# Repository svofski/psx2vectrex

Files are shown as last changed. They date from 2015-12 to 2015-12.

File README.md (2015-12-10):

# psx2vectrex

This project allows using a classic PlayStation controller with Vectrex. 

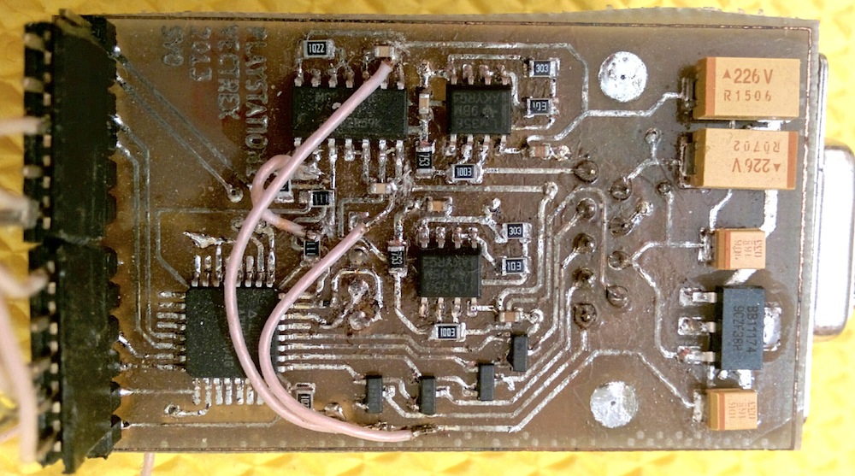
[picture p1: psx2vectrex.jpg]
Rusty PCB


Parts list:
 * 1x ATmega8
 * 1x MCP42010 dual-channel digital potentiometer
 * 2x LM358 opamp
 * 4x IRLML2502 (or any similar) logic-level n-channel MOSFETs
 * 1x LM1117-3V3 LDO, or equivalent
 * Some resistors and capacitors
 
Circuit in [PDF file](/kicad/vectrexmando.pdf)

The hardware is done in KiCAD. The design files are in [kicad](/kicad) directory.

To compile the source code WinAVR or avr-gcc/avr-libc is required. A programmer of choice is required to
bootstrap the microcontroller.

This adapter works excellent for me, but it's probably an overkill of a circuit for something as simple as this.

Here's a test video:

Joystick test video (http://www.youtube.com/watch?v=Hoa-xzlJ_dA)

---

2013-2015 Viacheslav Slavinsky, http://sensi.org/~svo

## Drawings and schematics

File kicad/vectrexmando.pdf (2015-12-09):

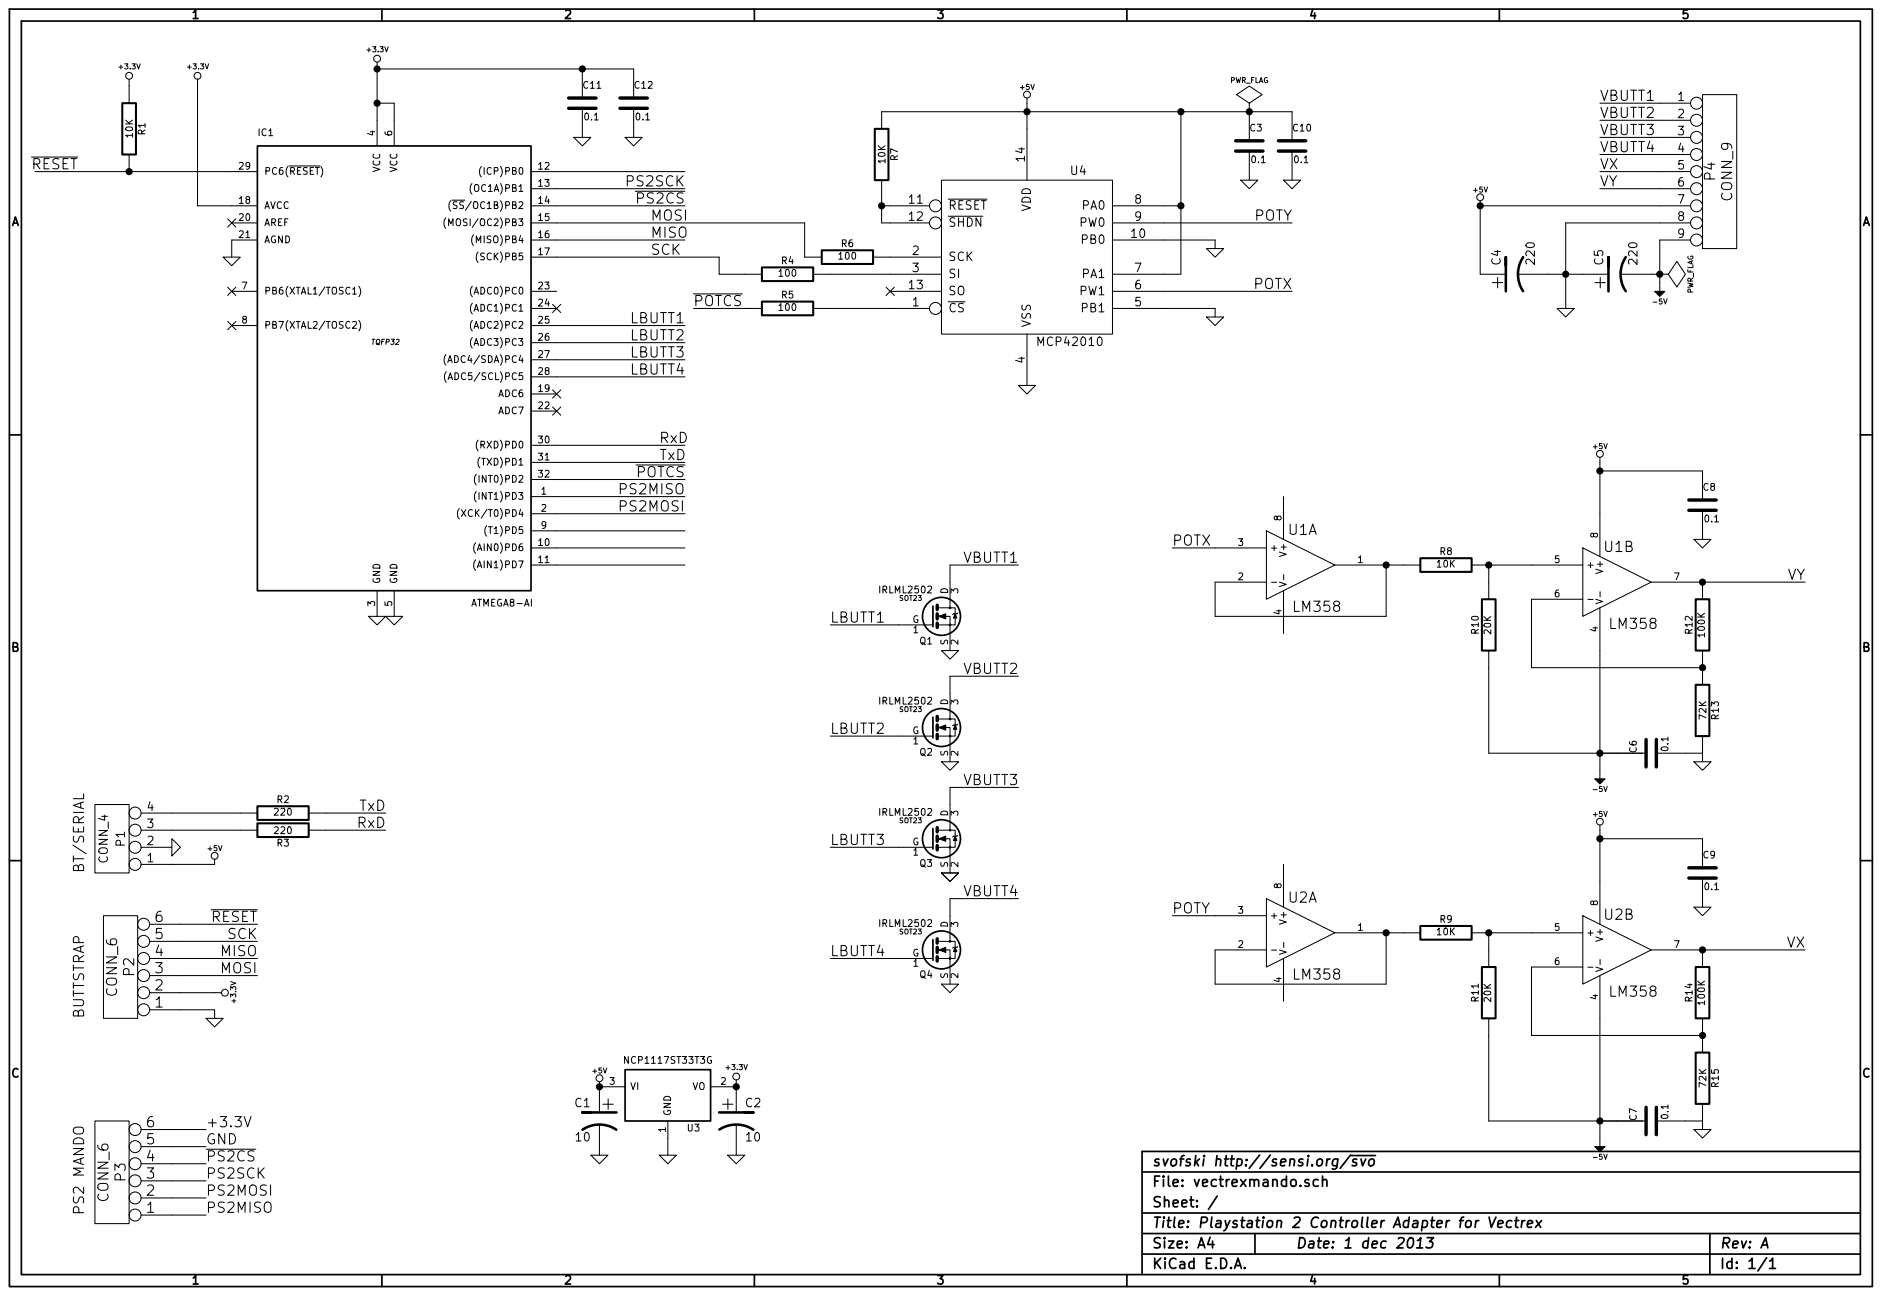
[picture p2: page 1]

LBUTT3
LBUTT4

svofski http://sensi.org/svo
Title: Playstation 2 Controller Adapter for Vectrex File: vectrexmando.sch Sheet: /

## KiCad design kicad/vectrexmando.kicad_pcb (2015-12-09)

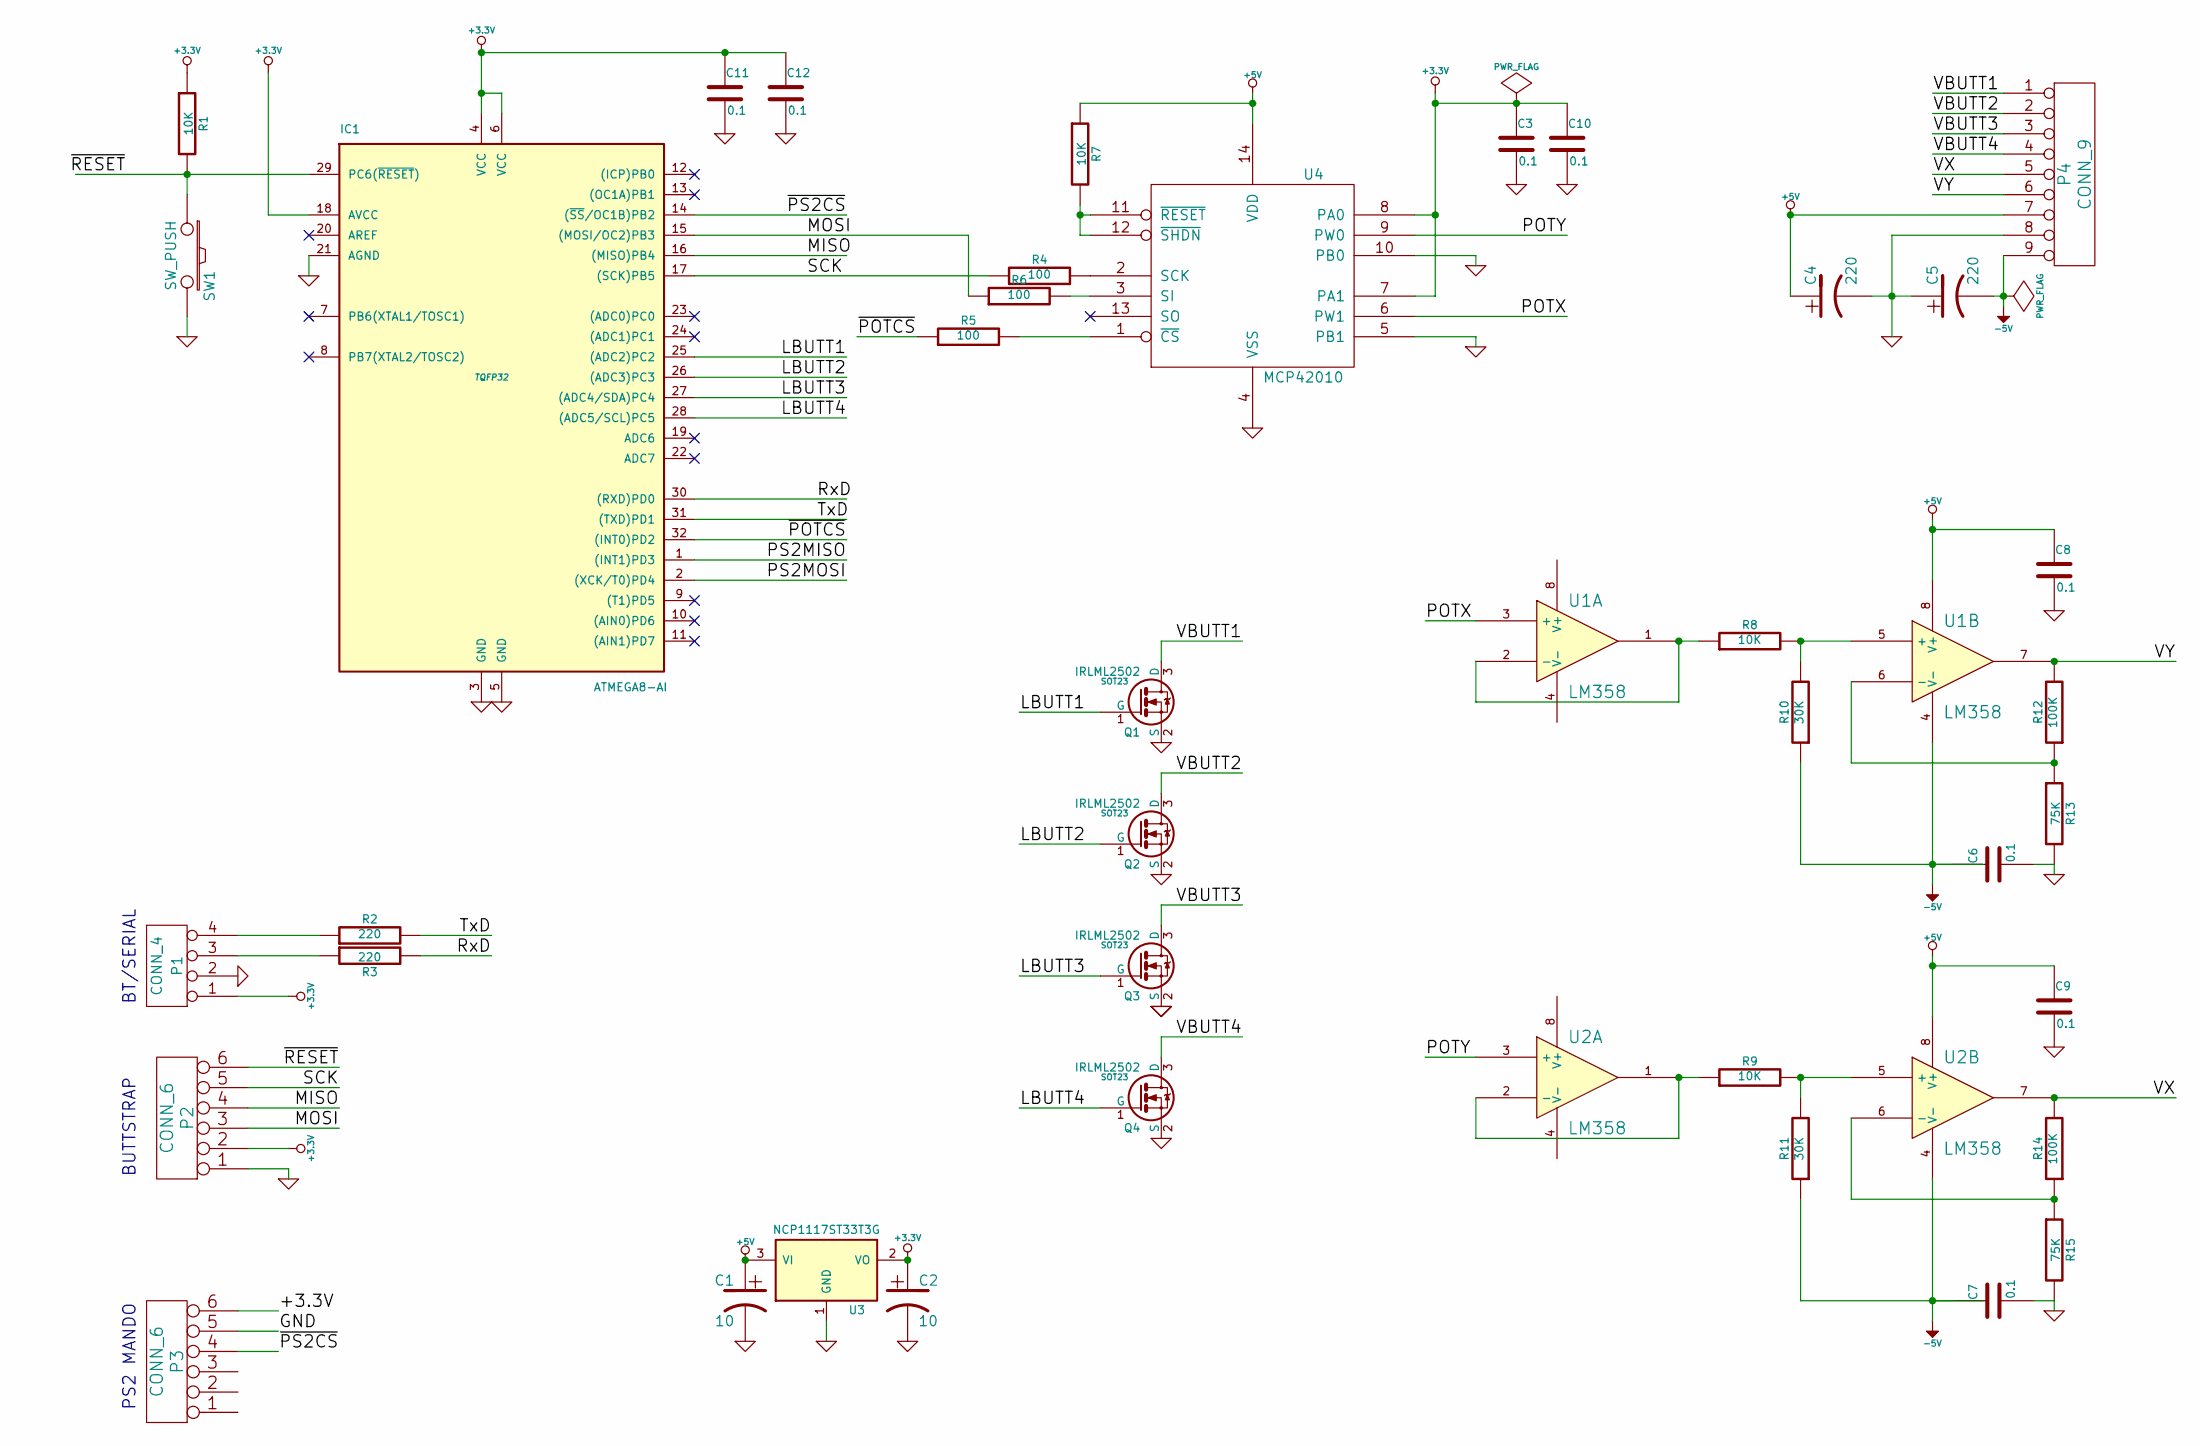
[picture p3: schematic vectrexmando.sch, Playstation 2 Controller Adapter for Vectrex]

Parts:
C1, C2: 10
C3, C6, C7, C8, C9, C10, C11, C12: 0.1
C4, C5: 220
IC1: ATMEGA8-AI; TQFP32
P1: CONN_4
P2, P3: CONN_6
P4: CONN_9
Q1, Q2, Q3, Q4: IRLML2502; SOT23
R1, R7, R8, R9: 10K
R2, R3: 220
R4, R5, R6: 100
R10, R11: 30K
R12, R14: 100K
R13, R15: 75K
SW1: SW_PUSH
U1, U2: LM358
U3: NCP1117ST33T3G
U4: MCP42010; 14-SOIC

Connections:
+3.3V: C2.1, C3.1, C10.1, C11.1, C12.1, IC1.4 (VCC), IC1.6 (VCC), IC1.18 (AVCC), P1.1, P2.2, P3.6, R1.1, U3.2 (VO), U4.7 (PA1), U4.8 (PA0)
+5V: C1.1, C4.1, C8.1, C9.1, P4.7, R7.1, U1.8 (V+), U2.8 (V+), U3.3 (VI), U4.14 (VDD)
-5V: C5.2, C6.1, C7.1, P4.9, R10.1, R11.1, U1.4 (V-), U2.4 (V-)
/LBUTT1: IC1.25 ((ADC2)PC2), Q1.1 (G)
/LBUTT2: IC1.26 ((ADC3)PC3), Q2.1 (G)
/LBUTT3: IC1.27 ((ADC4/SDA)PC4), Q3.1 (G)
/LBUTT4: IC1.28 ((ADC5/SCL)PC5), Q4.1 (G)
/MISO: IC1.16 ((MISO)PB4), P2.4
/MOSI: IC1.15 ((MOSI/OC2)PB3), P2.3, R6.1
/POTX: U1.3 (+), U4.6 (PW1)
/POTY: U2.3 (+), U4.9 (PW0)
/RxD: IC1.30 ((RXD)PD0), R3.2
/SCK: IC1.17 ((SCK)PB5), P2.5, R4.1
/TxD: IC1.31 ((TXD)PD1), R2.2
/VBUTT1: P4.1, Q1.3 (D)
/VBUTT2: P4.2, Q2.3 (D)
/VBUTT3: P4.3, Q3.3 (D)
/VBUTT4: P4.4, Q4.3 (D)
/VX: P4.5, R14.2, U2.7
/VY: P4.6, R12.2, U1.7
/~POTCS: IC1.32 ((INT0)PD2), R5.1
/~PS2CS: IC1.14 ((~SS~/OC1B)PB2), P3.4
/~RESET: IC1.29 (PC6(~RESET~)), P2.6, R1.2, SW1.1
GND: C1.2, C2.2, C3.2, C4.2, C5.1, C6.2, C7.2, C8.2, C9.2, C10.2, C11.2, C12.2, IC1.3 (GND), IC1.5 (GND), IC1.21 (AGND), P1.2, P2.1, P3.5, P4.8, Q1.2 (S), Q2.2 (S), Q3.2 (S), Q4.2 (S), R13.2, R15.2, SW1.2, U3.1 (GND), U4.4 (VSS), U4.5 (PB1), U4.10 (PB0)
unnamed: R7.2, U4.11 (~RESET), U4.12 (~SHDN)
unnamed: R5.2, U4.1 (~CS)
unnamed: R8.1, U1.1, U1.2 (-)
unnamed: R12.1, R13.1, U1.6 (-)
unnamed: R8.2, R10.2, U1.5 (+)
unnamed: P1.3, R3.1
unnamed: P1.4, R2.1
unnamed: R6.2, U4.3 (SI)
unnamed: R9.1, U2.1, U2.2 (-)
unnamed: R9.2, R11.2, U2.5 (+)
unnamed: R14.1, R15.1, U2.6 (-)
unnamed: R4.2, U4.2 (SCK)

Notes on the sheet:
BUTTSTRAP
PS2 MANDO
BT/SERIAL

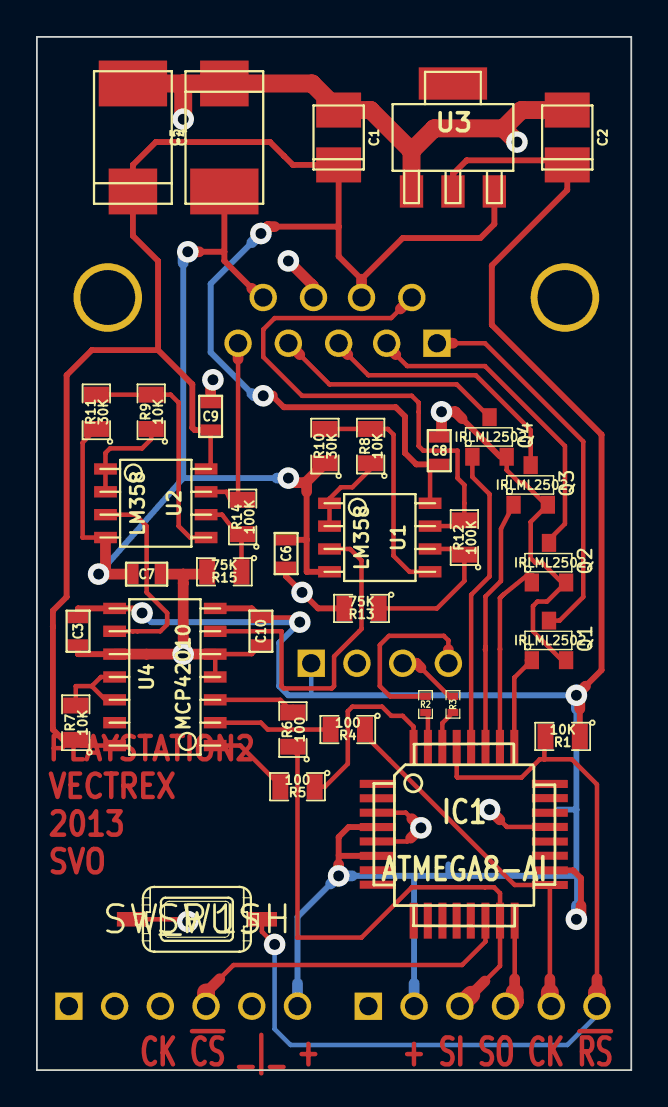
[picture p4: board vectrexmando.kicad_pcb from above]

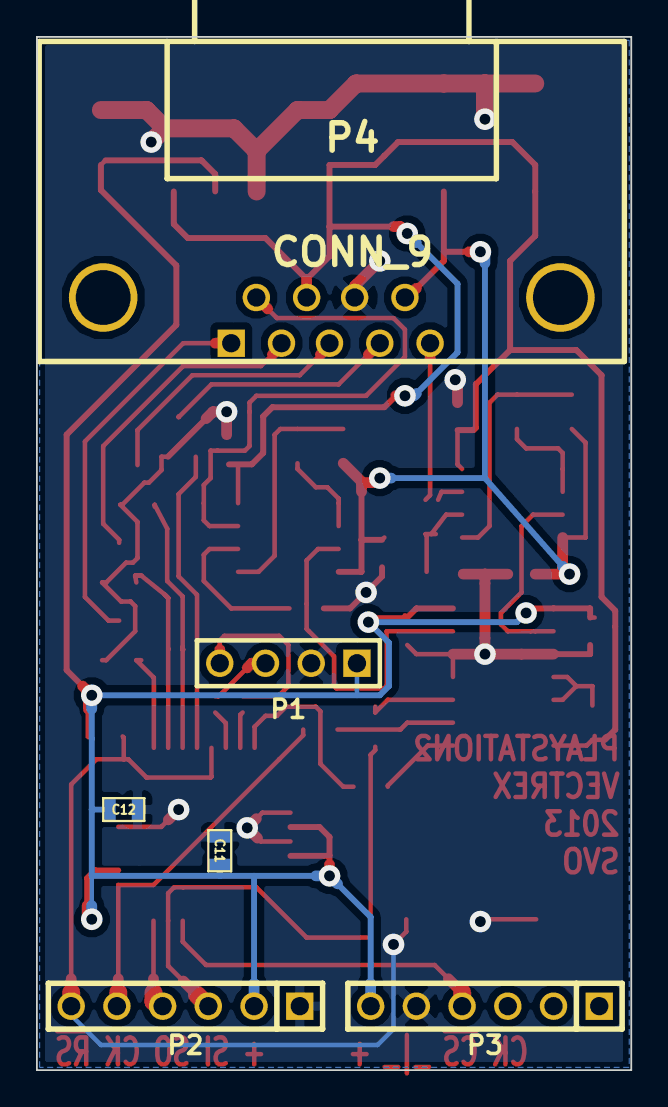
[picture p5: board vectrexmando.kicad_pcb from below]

Board: 2 copper layers, 33.0 x 57.4 mm, 41 parts (6 on the bottom side), 36 nets.

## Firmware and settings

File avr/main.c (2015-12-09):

///\file main.c
///\author Viacheslav Slavinsky
///
///\brief Vectroshnik main
///
/// This is the main source file. 
/// 
/// It has stuff.
///
/// \mainpage Vectroshnik: Playstation 2 controller with Vectrex
/// \section Description
/// Vectroshnik lets you play Vectrex with a fancy Playstation controller
/// \section Files
/// - main.c    main file
///
/// \section a How it works
/// Just works
/// 

#include <inttypes.h>
#include <avr/io.h>
#include <avr/interrupt.h>
#include <avr/sleep.h>
#include <avr/pgmspace.h>
#include <avr/delay.h>
#include <stdio.h>
#include <stdlib.h>

#include "usrat.h"
#include "ioconfig.h"
#include "spi.h"
#include "digipot.h"
#include "mando.h"

/// Program main
int main() {
    uint8_t x = 0x80, y = 0x80;
    uint8_t butt;

    usart_init(F_CPU/16/19200-1);
    printf_P(PSTR("\033[2J\033[HVECTROXNIK B%s (C)SVO 2013 PRESS @\n"), BUILDNUM);

    io_init();
    digipot_init();
    mando_init();
    spi_init();

    sei();

    mando_config();

    for(;;) {
        _delay_ms(1);

        mando_poll();
        mando_get_analog(&x, &y);
        digipot_set(x, y);

        mando_get_buttons(&butt);

        //printf_P(PSTR("%02x\n"), butt);

        BUTTASS(BUTT1, butt & 1);
        BUTTASS(BUTT2, butt & 2);
        BUTTASS(BUTT3, butt & 4);
        BUTTASS(BUTT4, butt & 8);

    }
}

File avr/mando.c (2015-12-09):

#include <stdio.h>
#include <avr/io.h>
#include <avr/pgmspace.h>
#include <avr/delay.h>
#include <string.h>
#include "ioconfig.h"
#include "spi.h"
#include "mando.h"

static uint8_t cmd_length;
static uint8_t buf[31];

void mando_init() {
    PS2SETUP;
    PS2SEL(1);
}

void mando_end(uint8_t arg) {
    _delay_us(20);
    PS2SEL(1);
}

void mando_byte(uint8_t arg) {
    _delay_us(20);
}

void mando_start(uint8_t arg) {
    // mad slow SPI
    SPSR = 0;

    // SPIE = 1: SPI interrupt enable
    // SPE  = 1: SPI enable
    // MSTR = 1: master
    // CPOL = 1: SCK idle high
    // CPHA = 0: sample on rising edge
    // DORD = 1: LSB first
    SPCR = _BV(SPIE) |  _BV(SPE) |  _BV(MSTR) | _BV(DORD) 
         | _BV(CPOL)
         | _BV(SPR1)
     //    | _BV(SPR0)
         ;
    
    _delay_us(25);
    PS2SEL(0);
    _delay_us(25);

    spi_start_exchange(buf, cmd_length, mando_byte, mando_end);
}

inline void mando_wait() {
    while(GETPS2SEL == 0);
}

uint8_t mando_get(uint8_t n) {
    return buf[n];
}

void dump() 
{
    for(int i = 0; i < 9 /*sizeof(buf)*/; i++) {
        printf_P(PSTR("%02x "), mando_get(i));
    }
    putchar('\n');
}

void mando_poll()
{
    mando_wait();

    memset(buf, 0, sizeof(buf));
    buf[0] = 0x01;
    buf[1] = 0x42;
    cmd_length = 9;
    
    spi_enqueue_transfer(SPI_TARGET_MANDO, mando_start);
    mando_wait();
    //dump();
}

static uint8_t dummy[] = {0x01};

static uint8_t poll_main[] = {0x01, 0x42, 0x00, 0x00, 0x00};
static uint8_t enter_config[]={0x01,0x43,0x00,0x01,0x00};
static uint8_t type_read[]={0x01,0x45,0x00,0x5A,0x5A,0x5A,0x5A,0x5A,0x5A};
static uint8_t type_read46_0[]={0x01,0x46,0x00,0x00,0x5A,0x5A,0x5A,0x5A,0x5A};
static uint8_t type_read46_1[]={0x01,0x46,0x00,0x01,0x5A,0x5A,0x5A,0x5A,0x5A};
static uint8_t type_read47_0[]={0x01,0x47,0x00,0x00,0x5A,0x5A,0x5A,0x5A,0x5A};
static uint8_t type_read4c_0[]={0x01,0x4c,0x00,0x00,0x5A,0x5A,0x5A,0x5A,0x5A};
static uint8_t type_read4c_1[]={0x01,0x4c,0x00,0x01,0x5A,0x5A,0x5A,0x5A,0x5A};
static uint8_t check_response[]={0x01,0x41,0x00,0x5a,0x5A,0x5A,0x5A,0x5A,0x5A};
static uint8_t exit_config[]={0x01,0x43,0x00,0x00,0x5A,0x5A,0x5A,0x5A,0x5A};
static uint8_t set_mode[]={0x01,0x44,0x00,0x01,0x03,0x00,0x00,0x00,0x00};

void mando_send(const uint8_t* bytes, uint8_t len) 
{
    mando_wait();
    memset(buf, 0x5a, sizeof(buf));
    memcpy(buf, bytes, len);
    cmd_length = len;
    spi_enqueue_transfer(SPI_TARGET_MANDO, mando_start);
    mando_wait();
    _delay_ms(5);
    dump();
}

void mando_config()
{

    mando_send(poll_main, 5);
    mando_send(enter_config, 5);
    //mando_send(type_read, 9);
    //mando_send(type_read46_0, 9);
    //mando_send(type_read46_1, 9);
    //mando_send(type_read47_0, 9);
    //mando_send(type_read4c_0, 9);
    //mando_send(type_read4c_1, 9);
    //mando_send(check_response, 9);
    mando_send(set_mode, 9);
    mando_send(exit_config, 9);
    return;
}

void mando_get_analog(uint8_t *x, uint8_t *y) 
{
    if (buf[1] == 0x73) {
        uint8_t up = buf[3] & 0x10; 
        uint8_t lt = buf[3] & 0x80;
        uint8_t rt = buf[3] & 0x20;
        uint8_t dn = buf[3] & 0x40;

        *x = buf[7];
        *y = 255 - buf[8];

        if (!up) *y = 0xff;
        if (!dn) *y = 0;
        if (!lt) *x = 0;
        if (!rt) *x = 0xff;
    } else {
        *x = *y = 0x80;
    }
}

void mando_get_buttons(uint8_t* butt)
{
    *butt = 0;

    if (buf[1] == 0x73) {
        uint8_t b1 = buf[4] & 0x80;
        uint8_t b2 = buf[4] & 0x40;
        uint8_t b3 = buf[4] & 0x20;
        uint8_t b4 = buf[4] & 0x10;

        *butt = (b1 ? 0 : 1) |
                (b2 ? 0 : 2) |
                (b3 ? 0 : 4) |
                (b4 ? 0 : 8);
    }
}

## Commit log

2015-12-09 psx controller to vectrex adapter
    [vectrexmando.dsn, vectrexmando.kicad_pcb, vectrexmando.sch]
2015-12-10 board picture
